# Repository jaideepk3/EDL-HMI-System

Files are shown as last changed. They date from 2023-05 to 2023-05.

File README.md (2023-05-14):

# HMI System for Corrosion Monitoring Product WEL-iPEC

This repository contains the development files for a Human Machine Interface (HMI) system designed for use with a corrosion monitoring product (iPEC-Probe). The HMI system includes a user interface with buttons connected to a microcontroller. Due to the unavailability of direct connection with the iPEC Probe, various sensors have been used to simulate data that will be displayed on the LCD screen.

## Files

The repository consists of the following files:

- **Packaging Enclosure CAD**: This folder contains CAD files for the packaging enclosure of the HMI system.

- **Board Files**: This folder contains the PCB design files for the microcontroller board.

- **HMI Code**: This folder contains the complex code that runs the HMI system.

- **Project Report**: This file is a comprehensive documented report of the entire project. It provides detailed information about the development process, implementation, and results. [Download Project Report](https://github.com/jaideepk3/EDL-HMI-System/blob/main/TUES-25_final_report.pdf)

## Project Description

### Aim
The aim of this project is to develop an HMI system that interfaces with the iPEC-Probe corrosion monitoring product. The HMI system will provide a user interface with buttons connected to a microcontroller. To simulate real-time data, sensors have been utilized instead of the actual iPEC Probe.

### Description
The project utilizes a Raspberry Pi Pico microcontroller board as the central controller for the HMI system. The microcontroller board interfaces with various buttons and an LCD screen. The buttons enable user interaction with the LCD screen, while the microcontroller controls the display based on the button inputs.

The HMI system displays real-time measurements obtained from various sensors, including the distance traveled from the scanning start point, rebar depth, rebar size, and other parameters. This provides users with an overview of the concrete structure's condition, enabling informed decision-making. The simulated values from the sensors facilitate comprehensive testing of the HMI system.

## Getting Started

To get started with the HMI system development, follow these steps:

1. Clone this repository to your local machine.
2. Navigate to the respective folders to access the CAD files, board design files, and HMI code.
3. Refer to the documentation provided in the report for further instructions.

## Additional Resources

- **Demo Video**: Watch a breadboard circuit demonstration of the HMI system in action. [Watch Demo Video](https://drive.google.com/file/d/1d6G7GhgJb7exQOc0swpD6kvzHQxaDGIW/view?usp=drivesdk)

- **Final Presentation**: Access the final presentation video for a detailed overview of the project. [View Final Presentation](https://drive.google.com/file/d/1m0dKYORe6IZ8-cWrcGXbmrLrGEMQUf9Z/view?usp=share_link)

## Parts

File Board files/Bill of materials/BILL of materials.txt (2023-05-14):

Partlist exported from C:/Users/seepa/AppData/Local/Temp/Neutron/ElectronFileOutput/8160/sch-04a15b2c-18d9-40eb-af97-f162f59256a9/Schematic v3.sch at 28-04-2023 18:17

Part               Value      Device                Package     Description                                      CATEGORY  DESCRIPTION                            MANUFACTURER MPN   OPERATING_TEMP OPERATING_TEMPERATURE PART_STATUS ROHS_COMPLIANCE ROHS_COMPLIANT SERIES SUB-CATEGORY THERMALLOSS TYPE       
GREEN_LED1         3MM_LED_TH 3MM_LED_TH            LED3MM                                                                                                                                                                                                                                                      
GREEN_LED2         3MM_LED_TH 3MM_LED_TH            LED3MM                                                                                                                                                                                                                                                      
GREEN_LED3         3MM_LED_TH 3MM_LED_TH            LED3MM                                                                                                                                                                                                                                                      
GREEN_LED4         3MM_LED_TH 3MM_LED_TH            LED3MM                                                                                                                                                                                                                                                      
GREEN_LED5         3MM_LED_TH 3MM_LED_TH            LED3MM                                                                                                                                                                                                                                                      
GREEN_LED6         3MM_LED_TH 3MM_LED_TH            LED3MM                                                                                                                                                                                                                                                      
JP2                PINHD-1X5  PINHD-1X5             1X05        PIN HEADER                                       CONNECTOR                                                                                                                                                  PIN-HEADER                          
JP4                PINHD-1X1  PINHD-1X1             1X01        PIN HEADER                                       CONNECTOR                                                                                                                                                  PIN-HEADER                          
JP5                PINHD-1X1  PINHD-1X1             1X01        PIN HEADER                                       CONNECTOR                                                                                                                                                  PIN-HEADER                          
JP6                PINHD-1X4  PINHD-1X4             1X04        PIN HEADER                                       CONNECTOR                                                                                                                                                  PIN-HEADER                          
JP7                PINHD-1X1  PINHD-1X1             1X01        PIN HEADER                                       CONNECTOR                                                                                                                                                  PIN-HEADER                          
JP10               PINHD-1X1  PINHD-1X1             1X01        PIN HEADER                                       CONNECTOR                                                                                                                                                  PIN-HEADER                          
JP11               PINHD-1X1  PINHD-1X1             1X01        PIN HEADER                                       CONNECTOR                                                                                                                                                  PIN-HEADER                          
JP12               PINHD-1X1  PINHD-1X1             1X01        PIN HEADER                                       CONNECTOR                                                                                                                                                  PIN-HEADER                          
JP14               PINHD-1X2  PINHD-1X2             1X02        PIN HEADER                                       CONNECTOR                                                                                                                                                  PIN-HEADER                          
JP15               PINHD-1X2  PINHD-1X2             1X02        PIN HEADER                                       CONNECTOR                                                                                                                                                  PIN-HEADER                          
LCD_SCREEN         ILI9341    ILI9341               ILI9341                                                                                                                                                                                                                                                     
R1                 10K        RESISTOR_1/4W_0207/10 0207/10                                                                                                                                                                                                                                                     
R2                 10K        RESISTOR_1/4W_0207/10 0207/10                                                                                                                                                                                                                                                     
R3                 10k        RESISTOR_1/4W_0207/10 0207/10                                                                                                                                                                                                                                                     
R4                 10K        RESISTOR_1/4W_0207/10 0207/10                                                                                                                                                                                                                                                     
R5                 10K        RESISTOR_1/4W_0207/10 0207/10                                                                                                                                                                                                                                                     
R6                 10k        RESISTOR_1/4W_0207/10 0207/10                                                                                                                                                                                                                                                     
R7                 10k        RESISTOR_1/4W_0207/10 0207/10                                                                                                                                                                                                                                                     
R8                 10k        RESISTOR_1/4W_0207/10 0207/10                                                                                                                                                                                                                                                     
R11                           PV36Y                 PV36Y       Rectangular Trimmer Potentiometers - PV36 Series Resistor  Lead Sealed Type Multiturn PV36 Series BOURNS       PV36Y                -55 to +125 °C        Active      ROHS Compliant                 PV36   Trimpot                  Lead Sealed
RASPBERRY_PI_PICO             RPI_PICO_IG-TH        RPI_PICO_TH                                                                                                                                                                                                                                                 
S1                 DTS-6      DTS-6                 DTS-6                                                                                                                                                                                                                                                       
S2                 DTS-6      DTS-6                 DTS-6                                                                                                                                                                                                                                                       
TEMPERATURE_SENSOR LM35CZ     LM35CZ                TO92        Single-Supply Centigrade Temperature Sensor

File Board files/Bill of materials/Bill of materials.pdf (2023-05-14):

Schematic v3

Part | Value | Device | Package
GREEN_LED1 | 3MM_LED_TH 3MM_LED_TH | LED3MM
GREEN_LED2 | 3MM_LED_TH 3MM_LED_TH | LED3MM
GREEN_LED3 | 3MM_LED_TH 3MM_LED_TH | LED3MM
GREEN_LED4 | 3MM_LED_TH 3MM_LED_TH | LED3MM
GREEN_LED5 | 3MM_LED_TH 3MM_LED_TH | LED3MM
GREEN_LED6 | 3MM_LED_TH 3MM_LED_TH | LED3MM
JP2 | PINHD-1X5 | PINHD-1X5 | 1X05
JP4 | PINHD-1X1 | PINHD-1X1 | 1X01
JP5 | PINHD-1X1 | PINHD-1X1 | 1X01
JP6 | PINHD-1X4 | PINHD-1X4 | 1X04
JP7 | PINHD-1X1 | PINHD-1X1 | 1X01
JP10 | PINHD-1X1 | PINHD-1X1 | 1X01
JP11 | PINHD-1X1 | PINHD-1X1 | 1X01
JP12 | PINHD-1X1 | PINHD-1X1 | 1X01
JP14 | PINHD-1X2 | PINHD-1X2 | 1X02
JP15 | PINHD-1X2 | PINHD-1X2 | 1X02
LCD_SCREEN | ILI9341 | ILI9341 | ILI9341
R1 | 10K | RESISTOR_1/4W_0207/10 0207/10
R2 | 10K | RESISTOR_1/4W_0207/10 0207/10
R3 | 10k | RESISTOR_1/4W_0207/10 0207/10
R4 | 10K | RESISTOR_1/4W_0207/10 0207/10
R5 | 10K | RESISTOR_1/4W_0207/10 0207/10
R6 | 10k | RESISTOR_1/4W_0207/10 0207/10
R7 | 10k | RESISTOR_1/4W_0207/10 0207/10
R8 | 10k | RESISTOR_1/4W_0207/10 0207/10
R11 | | PV36Y | PV36Y
RASPBERRY_PI_PICO | | RPI_PICO_IG-TH | RPI_PICO_TH
S1 | DTS-6 | DTS-6 | DTS-6
S2 | DTS-6 | DTS-6 | DTS-6
TEMPERATURE_SENSOR LM35CZ | LM35CZ | TO92

Description | CATEGORY
PIN HEADER | CONNECTOR
PIN HEADER | CONNECTOR
PIN HEADER | CONNECTOR
PIN HEADER | CONNECTOR
PIN HEADER | CONNECTOR
PIN HEADER | CONNECTOR
PIN HEADER | CONNECTOR
PIN HEADER | CONNECTOR
PIN HEADER | CONNECTOR
PIN HEADER | CONNECTOR

Rectangular Trimmer Potentiometers - PV36 Series Resistor

Single-Supply Centigrade Temperature Sensor

DESCRIPTION | MANUFACTURER MPN | OPERATING_TEMP
Lead Sealed Type Multiturn PV36 Series BOURNS | PV36Y

OPERATING_TEMPERATURE PART_STATUS ROHS_COMPLIANCE ROHS_COMPLIANT SERIES

-55 to +125 °C | Active | ROHS Compliant | PV36

SUB-CATEGORY THERMALLOSS TYPE

PIN-HEADER
PIN-HEADER
PIN-HEADER
PIN-HEADER
PIN-HEADER
PIN-HEADER
PIN-HEADER
PIN-HEADER
PIN-HEADER
PIN-HEADER
Trimpot | Lead Sealed

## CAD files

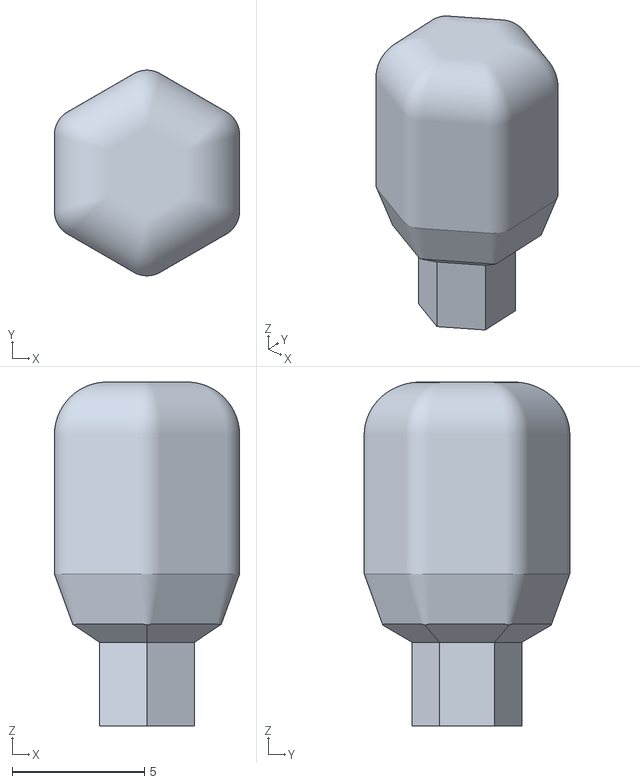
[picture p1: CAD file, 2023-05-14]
CAD files/3d print/Knob.stl
7.00 x 7.77 x 13.0

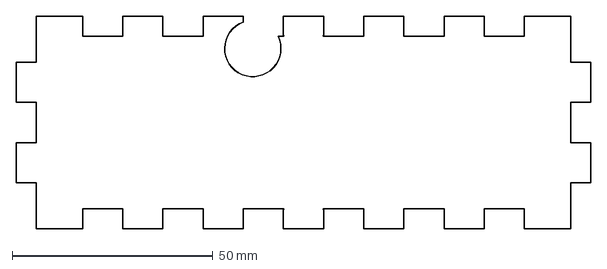
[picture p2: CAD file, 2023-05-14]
CAD files/lasercut/body1.dxf
143.2 x 53.0 mm

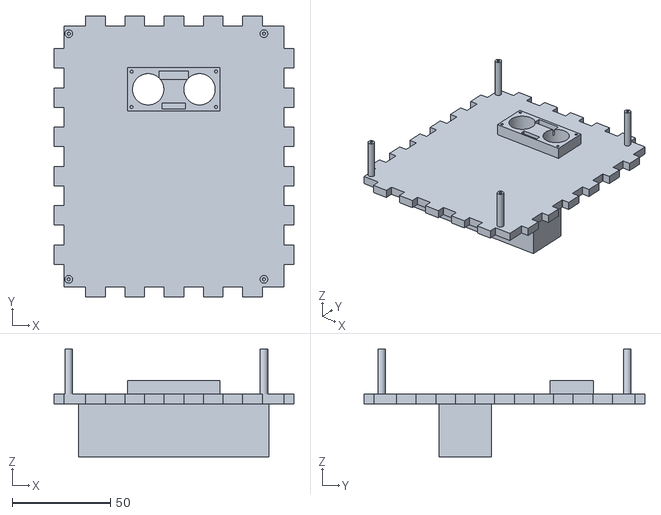
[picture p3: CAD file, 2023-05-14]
CAD files/3d print/body6.stl
122.3 x 143.2 x 55.0

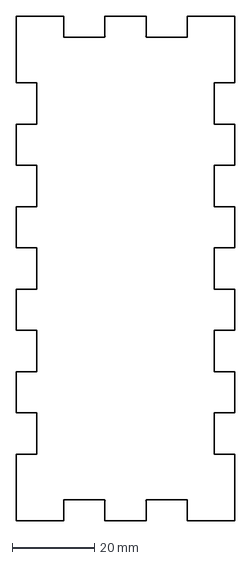
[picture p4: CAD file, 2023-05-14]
CAD files/lasercut/body5.dxf
53.0 x 122.3 mm

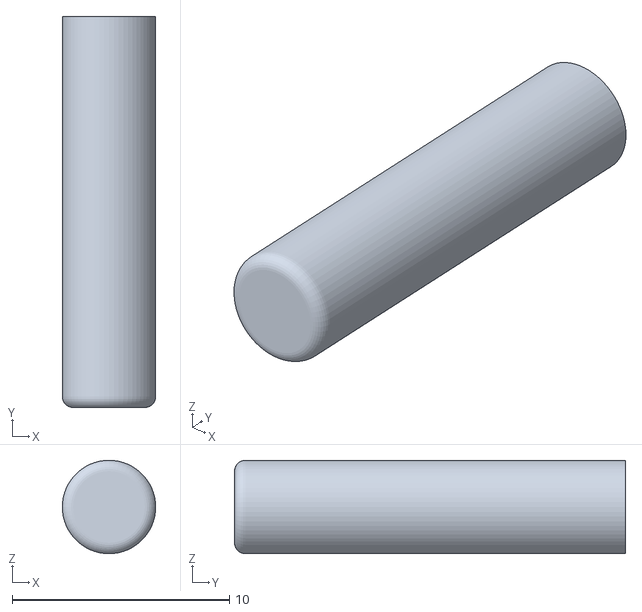
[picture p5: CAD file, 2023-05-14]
CAD files/3d print/Button_cap_X2.stl
4.30 x 18.0 x 4.30

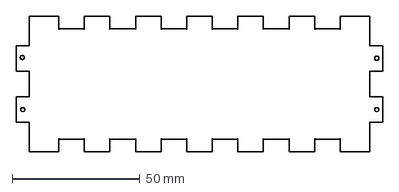
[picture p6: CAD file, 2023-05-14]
CAD files/lasercut/body4.dxf
143.2 x 53.0 mm

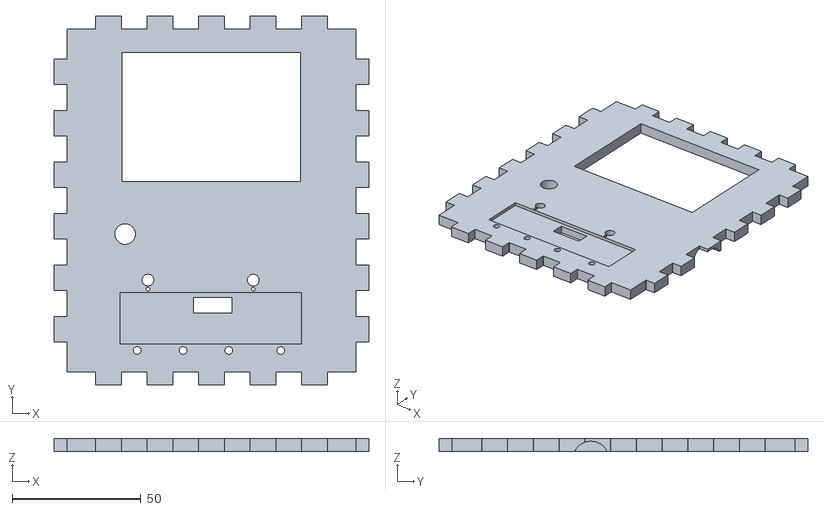
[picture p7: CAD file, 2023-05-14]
CAD files/3d print/body3.stl
122.3 x 143.2 x 5.00

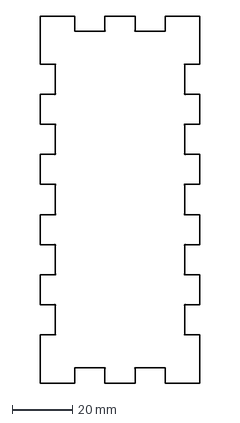
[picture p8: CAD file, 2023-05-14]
CAD files/lasercut/body2.dxf
53.0 x 122.3 mm

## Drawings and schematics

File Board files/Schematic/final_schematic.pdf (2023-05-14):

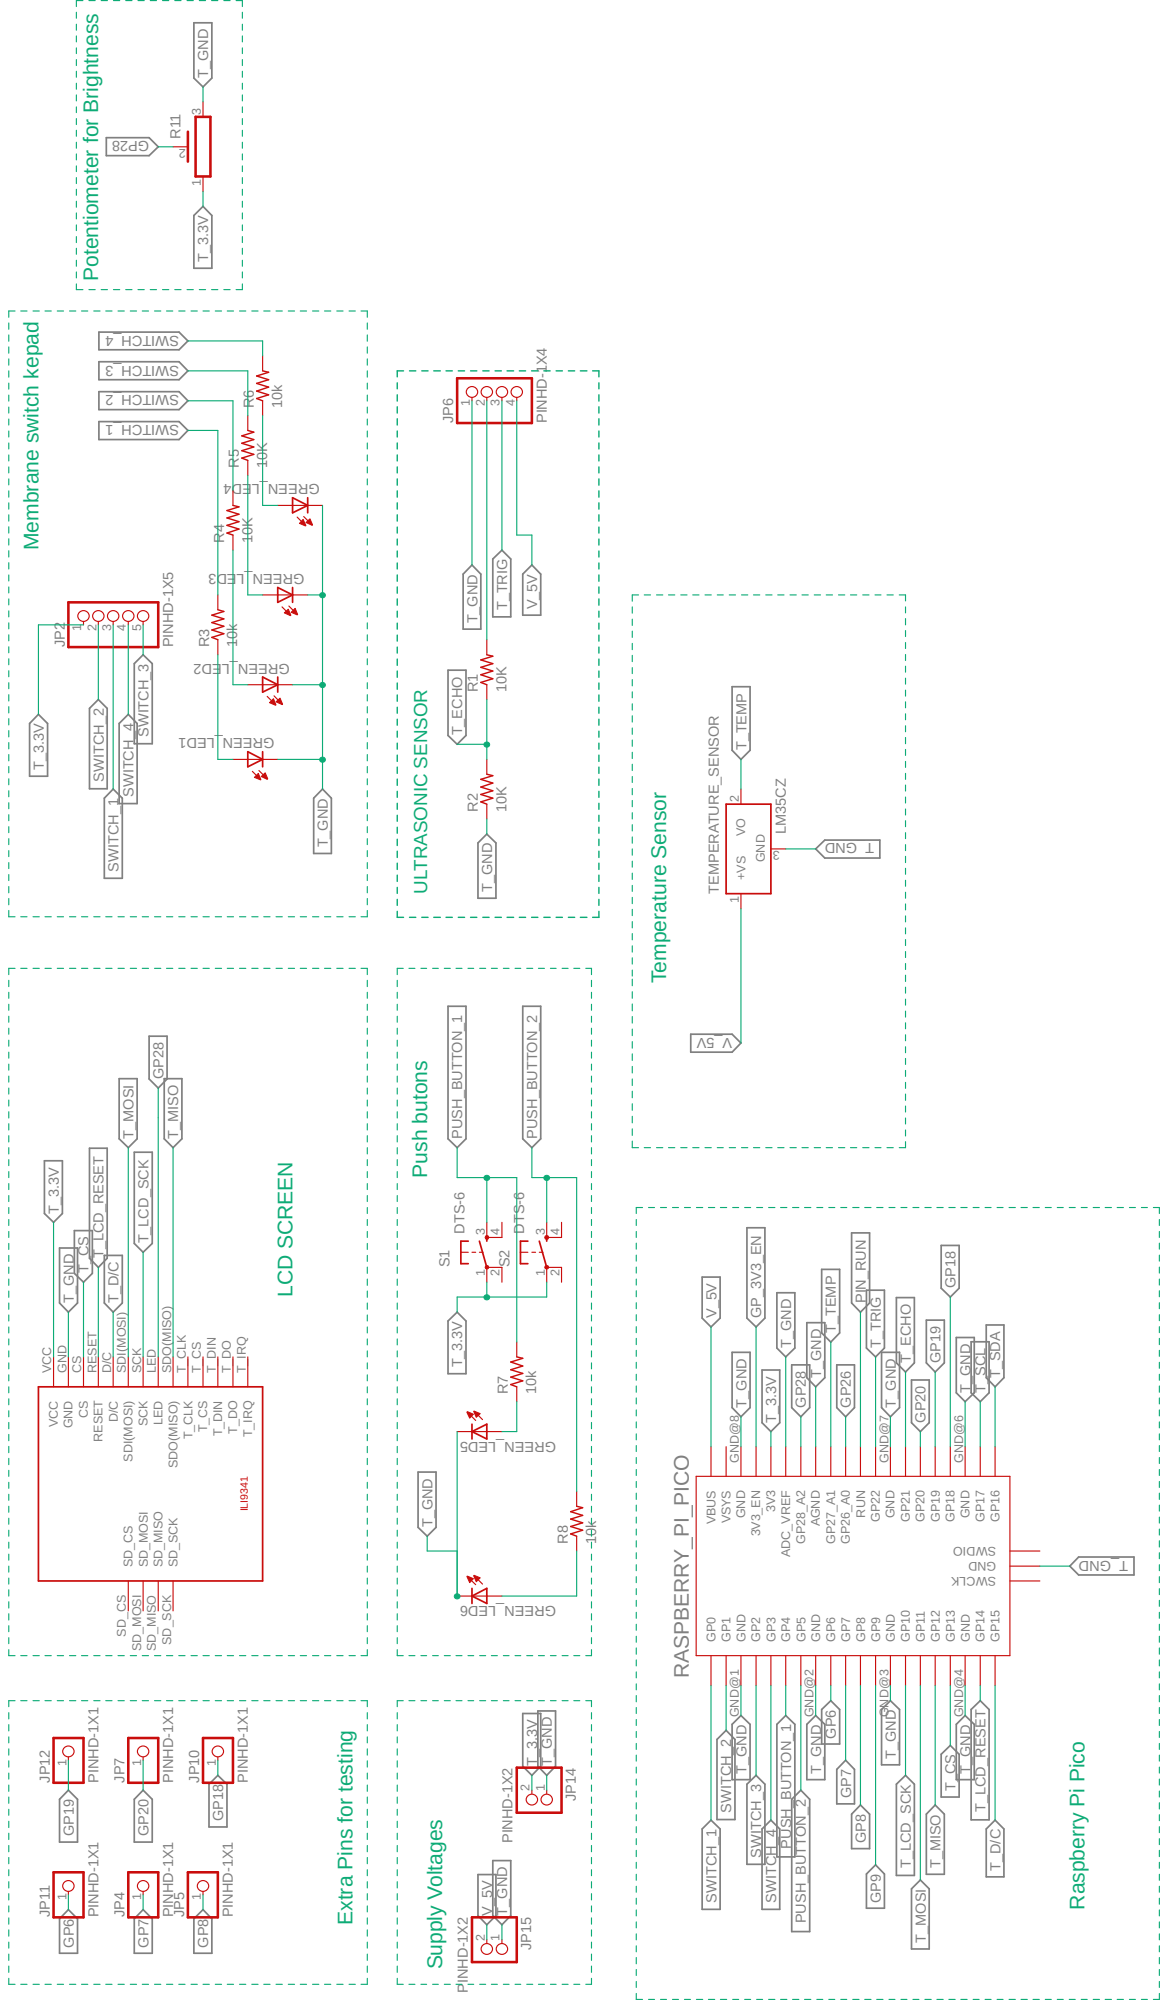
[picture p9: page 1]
5 T_ECHO T_ECHO T_TEMP T_TEMP T_3.3V T_3.3V T_3.3V T_3.3V T_3.3V T_3.3V T_GND T_GND T_GND

LM35CZ 10K 10K 10k 10K 10K 10k 10k 10k PINHD-1X1 PINHD-1X1 PINHD-1X1 PINHD-1X1 PINHD-1X1 PINHD-1X1 PINHD-1X2 PINHD-1X2 DTS-6 DTS-6 PINHD-1X4 PINHD-1X5 RASPBERRY_PI_PICO GP0 GP1 GP2 GP3 GP4 GP5 GP6 GP7 GP8 GP9 GP10 GP11 GP12 GP13 GP14 GP15 RUN GP22 GP21 GP20 GP19 GP18 GP17 GP16 GP27_A1 GP26_A0 AGND GP28_A2 ADC_VREF 3V3 3V3_EN VBUS VSYS

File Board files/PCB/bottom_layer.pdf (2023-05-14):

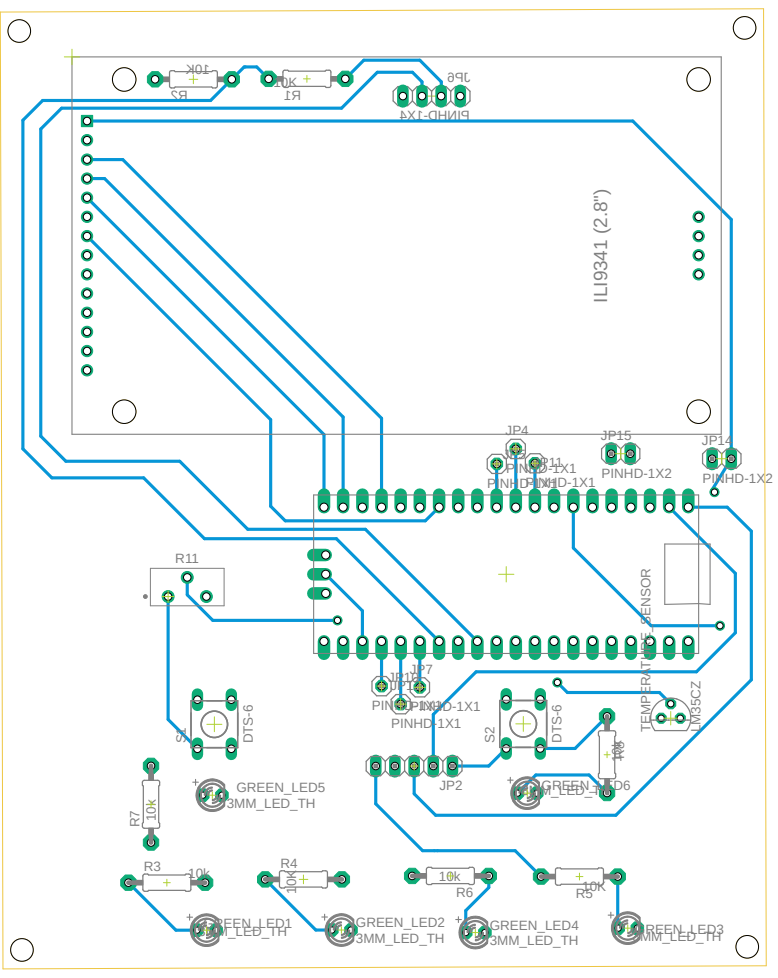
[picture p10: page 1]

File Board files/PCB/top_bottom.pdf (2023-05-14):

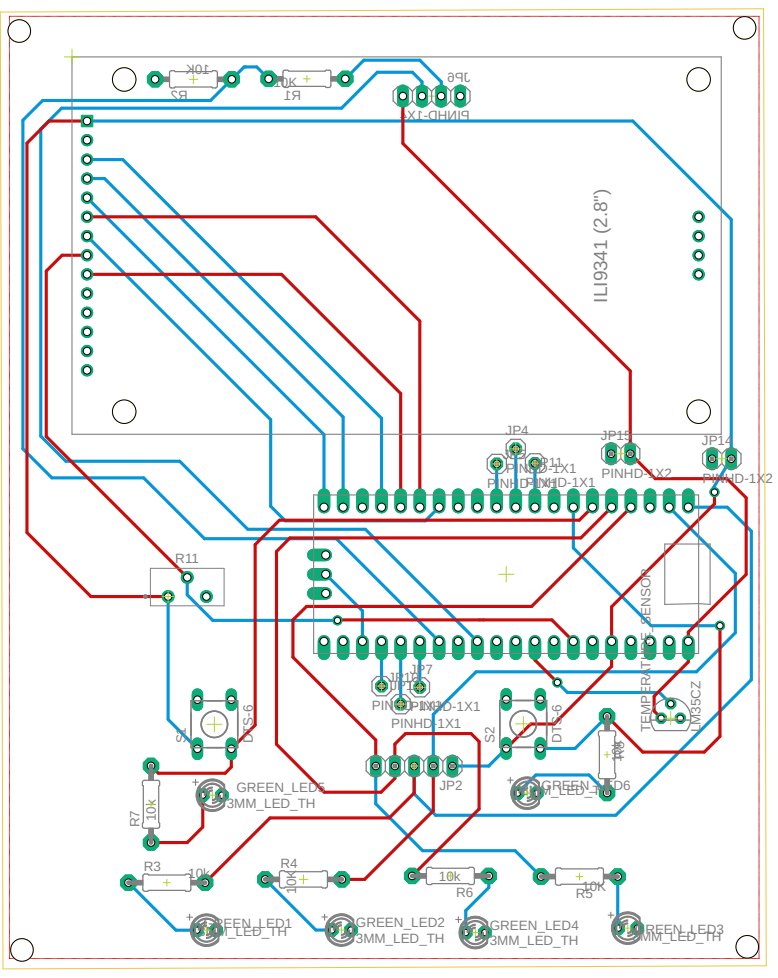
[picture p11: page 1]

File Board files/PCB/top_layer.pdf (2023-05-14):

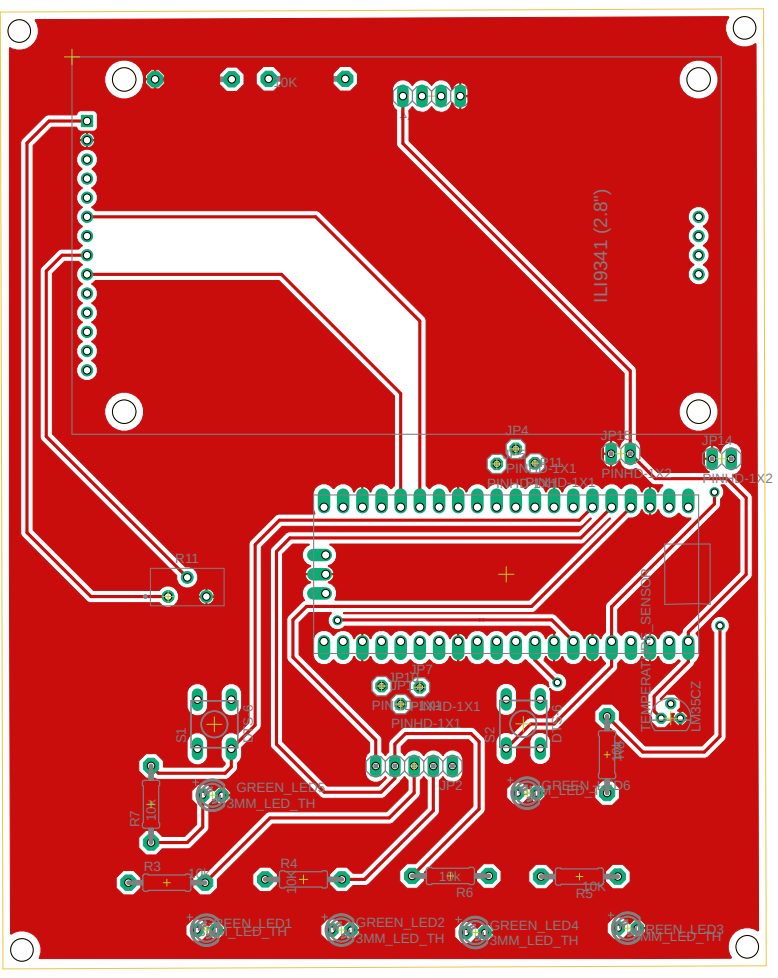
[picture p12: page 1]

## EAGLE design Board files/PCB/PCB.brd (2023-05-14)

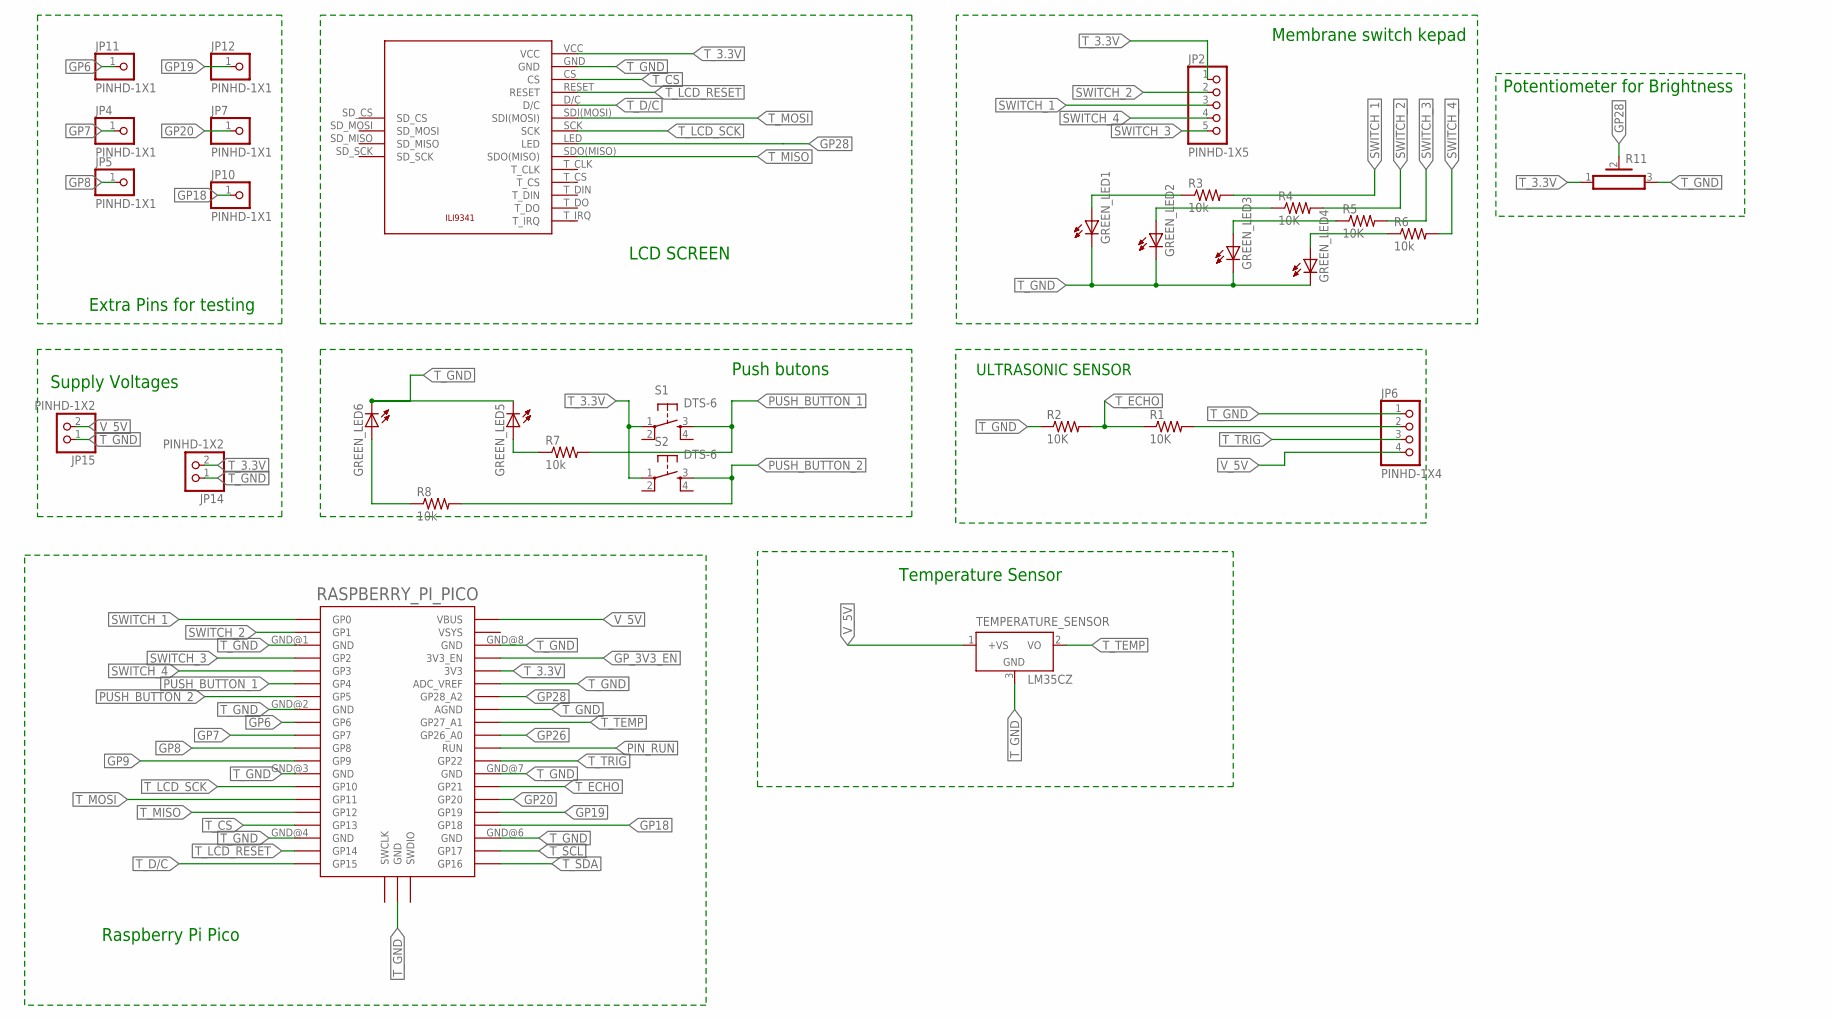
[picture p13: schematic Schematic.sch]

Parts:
GREEN_LED1, GREEN_LED2, GREEN_LED3, GREEN_LED4, GREEN_LED5, GREEN_LED6: 3MM_LED_TH; LED3MM
JP2: PINHD-1X5; 1X05
JP4, JP5, JP7, JP10, JP11, JP12: PINHD-1X1; 1X01
JP6: PINHD-1X4; 1X04
JP14, JP15: PINHD-1X2; 1X02
LCD_SCREEN: ILI9341
R1, R2, R4, R5: 10K; 0207/10
R3, R6, R7, R8: 10k; 0207/10
R11: PV36Y
RASPBERRY_PI_PICO: RPI_PICO_IG-TH; RPI_PICO_TH
S1, S2: DTS-6
TEMPERATURE_SENSOR: LM35CZ; TO92

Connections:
GP6: JP11.1, RASPBERRY_PI_PICO.GP6
GP7: JP4.1, RASPBERRY_PI_PICO.GP7
GP8: JP5.1, RASPBERRY_PI_PICO.GP8
GP9: RASPBERRY_PI_PICO.GP9
GP18: JP10.1, RASPBERRY_PI_PICO.GP18
GP19: JP12.1, RASPBERRY_PI_PICO.GP19
GP20: JP7.1, RASPBERRY_PI_PICO.GP20
GP26: RASPBERRY_PI_PICO.GP26_A0
GP28: LCD_SCREEN.LED, R11.2, RASPBERRY_PI_PICO.GP28_A2
GP_3V3_EN: RASPBERRY_PI_PICO.3V3_EN
unnamed: JP6.2, R1.2
unnamed: GREEN_LED4.A, R6.1
unnamed: GREEN_LED3.A, R5.1
unnamed: GREEN_LED2.A, R4.1
unnamed: GREEN_LED1.A, R3.1
unnamed: GREEN_LED5.A, R7.1
unnamed: GREEN_LED6.A, R8.1
PIN_RUN: RASPBERRY_PI_PICO.RUN
PUSH_BUTTON_1: R7.2, RASPBERRY_PI_PICO.GP4, S1.3
PUSH_BUTTON_2: R8.2, RASPBERRY_PI_PICO.GP5, S2.3
SWITCH_1: JP2.3, R3.2, RASPBERRY_PI_PICO.GP0
SWITCH_2: JP2.2, R4.2, RASPBERRY_PI_PICO.GP1
SWITCH_3: JP2.5, R5.2, RASPBERRY_PI_PICO.GP2
SWITCH_4: JP2.4, R6.2, RASPBERRY_PI_PICO.GP3
T_3.3V: JP2.1, JP14.2, LCD_SCREEN.VCC, R11.1, RASPBERRY_PI_PICO.3V3, S1.1, S2.1
T_CS: LCD_SCREEN.CS, RASPBERRY_PI_PICO.GP13
T_D/C: LCD_SCREEN.D/C, RASPBERRY_PI_PICO.GP15
T_ECHO: R1.1, R2.2, RASPBERRY_PI_PICO.GP21
T_GND: GREEN_LED1.K (C), GREEN_LED2.K (C), GREEN_LED3.K (C), GREEN_LED4.K (C), GREEN_LED5.K (C), GREEN_LED6.K (C), JP6.1, JP14.1, JP15.1, LCD_SCREEN.GND, R2.1, R11.3, RASPBERRY_PI_PICO.ADC_VREF, RASPBERRY_PI_PICO.AGND, RASPBERRY_PI_PICO.GND@1 (GND), RASPBERRY_PI_PICO.GND@2 (GND), RASPBERRY_PI_PICO.GND@3 (GND), RASPBERRY_PI_PICO.GND@4 (GND), RASPBERRY_PI_PICO.GND@5 (GND), RASPBERRY_PI_PICO.GND@6 (GND), RASPBERRY_PI_PICO.GND@7 (GND), RASPBERRY_PI_PICO.GND@8 (GND), TEMPERATURE_SENSOR.3 (GND)
T_LCD_RESET: LCD_SCREEN.RESET, RASPBERRY_PI_PICO.GP14
T_LCD_SCK: LCD_SCREEN.SCK, RASPBERRY_PI_PICO.GP10
T_MISO: LCD_SCREEN.SDO(MISO), RASPBERRY_PI_PICO.GP12
T_MOSI: LCD_SCREEN.SDI(MOSI), RASPBERRY_PI_PICO.GP11
T_SCL: RASPBERRY_PI_PICO.GP17
T_SDA: RASPBERRY_PI_PICO.GP16
T_TEMP: RASPBERRY_PI_PICO.GP27_A1, TEMPERATURE_SENSOR.2 (VO)
T_TRIG: JP6.3, RASPBERRY_PI_PICO.GP22
V_5V: JP6.4, JP15.2, RASPBERRY_PI_PICO.VBUS, TEMPERATURE_SENSOR.1 (+VS)

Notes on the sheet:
LCD SCREEN
ULTRASONIC SENSOR
Membrane switch kepad
Push butons
Supply Voltages
Extra Pins for testing
Raspberry Pi Pico
Potentiometer for Brightness
Temperature Sensor

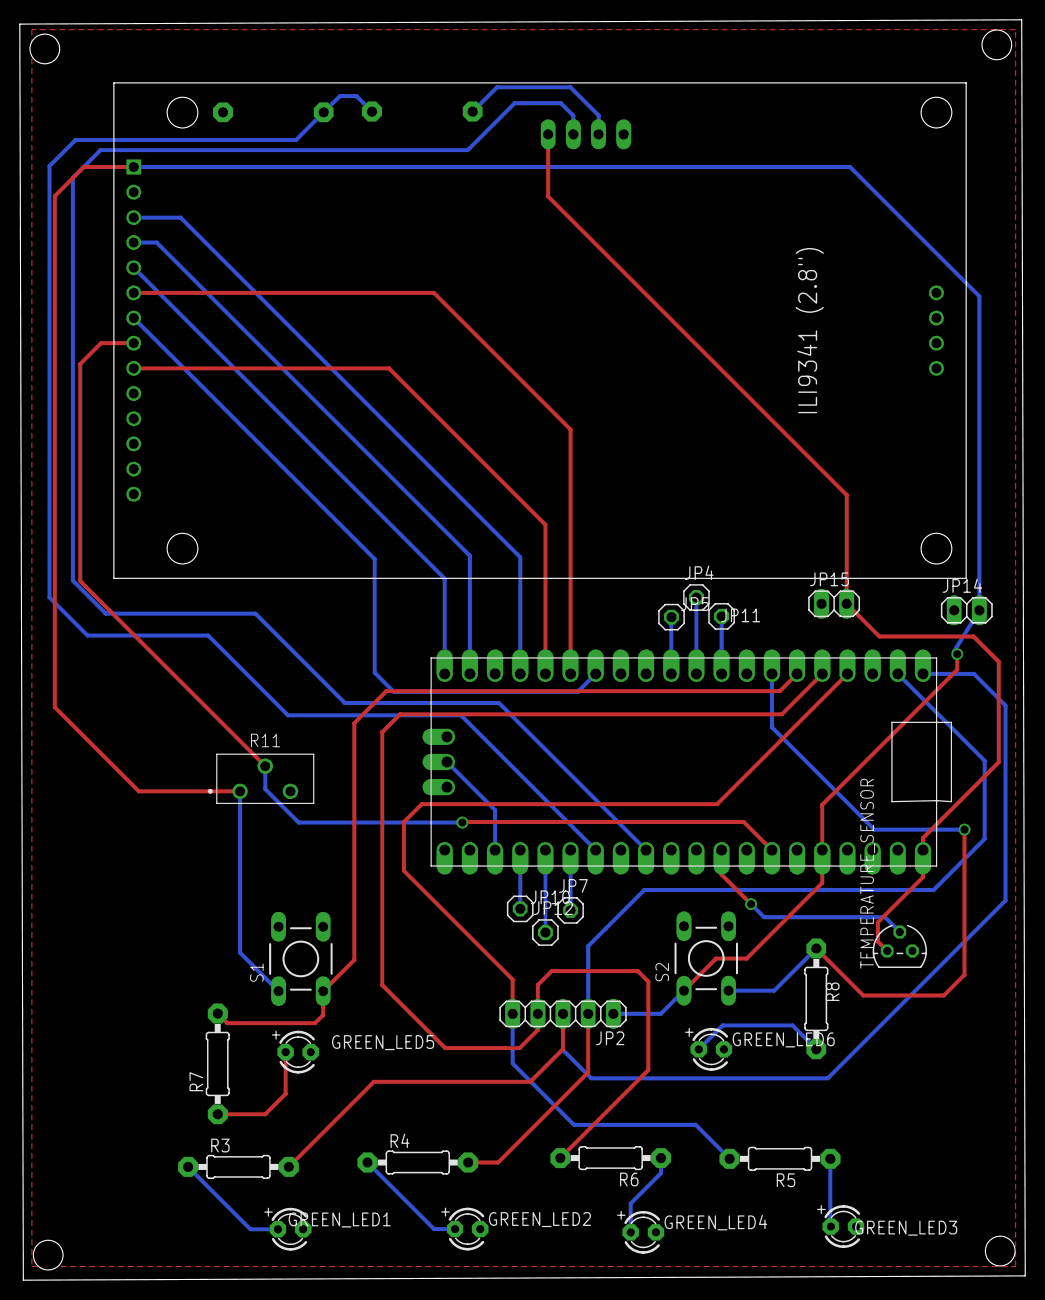
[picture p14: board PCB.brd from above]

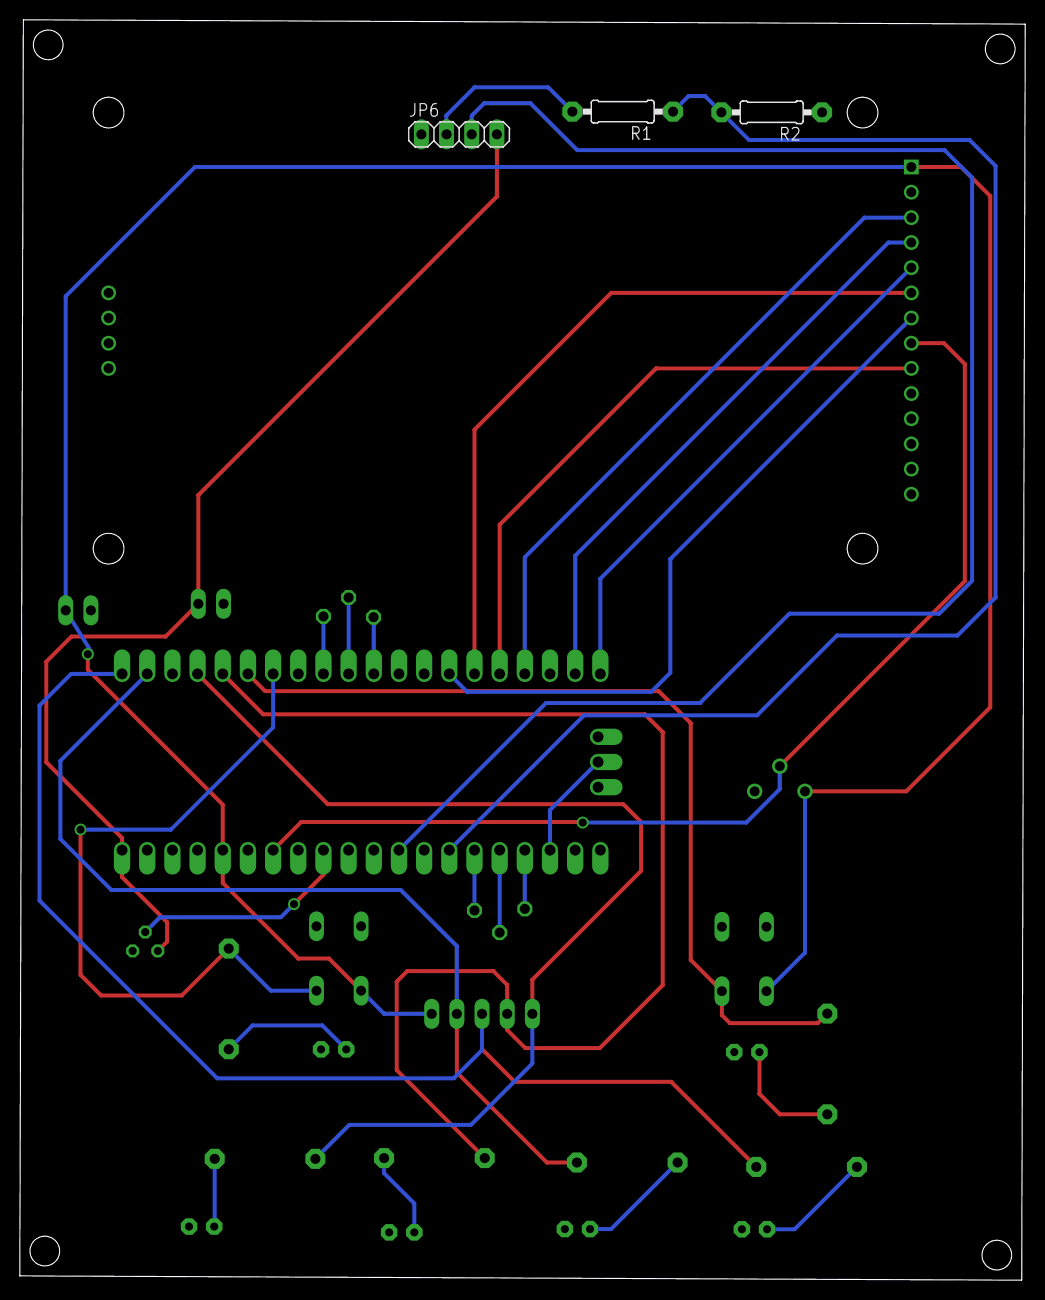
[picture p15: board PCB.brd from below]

Board: 2 copper layers, 101.5 x 127.2 mm, 30 parts (3 on the bottom side), 32 nets.

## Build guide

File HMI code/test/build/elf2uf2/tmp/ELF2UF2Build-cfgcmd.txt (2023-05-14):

cmd='C:/Program Files/CMake/bin/cmake.exe;-GMinGW Makefiles;-S;<SOURCE_DIR><SOURCE_SUBDIR>;-B;<BINARY_DIR>'

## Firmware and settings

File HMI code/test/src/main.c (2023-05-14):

#include "main.h"
#include "ui.h"
#include "interface.h"
#include "temp.h"
#include "pico/time.h"
#include <string.h>
#include "pico/stdlib.h"
#include "hardware/gpio.h"
#include "hardware/adc.h"
#include "./screens/simulator_screen.h"
#include "./screens/distance_screen.h"
#include "simulation.h"
#include "distance.h"
 #include "./screens/popup.h"
#include<stdint.h>
#include<stdlib.h>
#include "brightness.h"
float univ = 27;
int NUM_SCREENS = 4;
uint32_t curr_brightness =  0;
 uint8_t currPopupPage =0;
 int lastDetectedPress = 0;
GPU_Color BG_COLOR= BLACK;
int presses = 0;

bool pauseSimulation = false;
static uint32_t _lastDrawTime;
Screen currScreen = DISTANCE_SCREEN;
#define INTERVAL 5*1e6

float random_wait_time(int maxtime){
    return  (((float) rand() / (float)(RAND_MAX))*maxtime);
}

  
int end=-1;
int dist;
int new_draw_time;


//update rebar depth on simulation screen 
void distance_callback(){
    dist = (int)calc_distance();
    end+=1;
    if(end>=Q_SIZE)end=Q_SIZE;
    simulate(end,dist);
    busy_wait_ms(130);
}

void DoMainLoop()
{   
    _lastDrawTime = IF_GetCurrentTime();
  distance_sensor_init();
  bar_init();
  temp_sensor_init();
  simulation_init();
  distance_screen_init();
 
    int old=time_us_32();
    lastDetectedPress = time_us_32();
 

    while (1)
    {
       int now = time_us_32();
        //Register left keyboard events
        Keyboard();

        //update UI if popup isn't opened and achieve desired FPS
             if (( new_draw_time - _lastDrawTime > (ONE_SECOND/GPU_TARGET_FPS)) && !popup_opened)
             {
              _lastDrawTime = new_draw_time;
              GPU_Render(); //update UI on LCD screen
       } new_draw_time= IF_GetCurrentTime();
 
//rebar simulation done at regular intervals      
if((now-old>INTERVAL)&&(!pauseSimulation)){
    distance_callback();
    old=now;
}

//update UI on LCD based on current screen  
  if(currScreen ==DISTANCE_SCREEN){
   distance_screen_init();
  }
  else if(currScreen==PARAMS_SCREEN){
    update_temperature();
    display_png();//thermometer image

  }else if(currScreen == SIMULATION_SCREEN){
    display_simulation(end);
  }else if(currScreen == ADJUST_BRIGHTNESS_SCREEN) {
    brightness_screen_init();
    update_brightness();
    increase_brightness(curr_brightness);
 
  } else{
  GPU_ClearFramebuffers();
  }
  	 
  if(popup_opened){GPU_DrawFilledRectangle(BLACK,40,TOP_MARGIN,270,160);}
 
  
    }
}

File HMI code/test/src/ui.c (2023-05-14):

#include "ui.h"
#include "fonts.h"
#include <string.h>
#include <math.h>
#include "pico/time.h"
#include <stdio.h>
#include "interface.h"
//buffer to store pixel values
 uint16_t _framebuffer[GPU_X*GPU_Y];  // GPU VRAM (16bits per color)


void GPU_Init()
{  GPU_ClearFramebuffers();
}
 

void GPU_ClearFramebuffers()
{
    memset(_framebuffer, 0, sizeof(_framebuffer));
}



#define SHOW_FPS

#ifdef SHOW_FPS
uint32_t oldTime = 0;
#endif

uint32_t getMinutes(){
    uint32_t nowTime = IF_GetCurrentTime();
    uint32_t currentTime = to_ms_since_boot(nowTime)/1000;
        uint8_t seconds = ((currentTime/10%60)*10)%60;
     uint32_t minutes= currentTime/60;
     return minutes;
}

//update LCD screen pixel values by sending buffer data
void GPU_Render()
{ 
#ifdef SHOW_FPS
	char t[25] = "";
	uint16_t len = 0;
	uint32_t nowTime = IF_GetCurrentTime();

#define COLOR_INFO RGB(217,207,38)
	if (oldTime != nowTime)
	{   
		uint16_t fps = (float)ONE_SECOND / (float)(nowTime-oldTime);
        uint32_t currentTime = to_ms_since_boot(nowTime)/1000;
        uint8_t seconds = ((currentTime/10%60)*10)%60;
        uint32_t minutes= currentTime/60;
		len = sprintf(t, "On Time = %d min %d sec", minutes, seconds);
   
        GPU_DrawFilledRectangle(BG_COLOR,GPU_X-len*fontDescription[1].width - 10,0,
        len*fontDescription[1].width+30,fontDescription[1].height+1);
		GPU_DrawText(COLOR_INFO, &fontDescription[1], GPU_X-len*fontDescription[1].width, 0, t, len);
	}

	oldTime = nowTime;

#endif
    IF_DrawScreen((uint8_t *)_framebuffer, sizeof(_framebuffer));
}

///////////////////////////////////////////////

void GPU_DrawPixel(GPU_Color color, uint16_t x, uint16_t y)
{
    if (x >= GPU_X || y >= GPU_Y)
        return;
    uint16_t * pix = &_framebuffer[(GPU_X-x-1)*GPU_Y+y];
    (*pix) = (uint16_t) color;
}

void GPU_DrawLine(GPU_Color color, int16_t x0, int16_t y0, int16_t x1, int16_t y1)
{
    // Bresenhams line algorithm
    x0 = (x0 >= GPU_X) ? GPU_X-1 : x0;
    x1 = (x1 >= GPU_X) ? GPU_X-1 : x1;
    y0 = (y0 >= GPU_Y) ? GPU_Y-1 : y0;
    y1 = (y1 >= GPU_Y) ? GPU_Y-1 : y1;
    int16_t dx =  x1>x0 ? x1-x0 : x0-x1;
    int16_t sx = x0<x1 ? 1 : -1;
    int16_t dy = y1 > y0 ? -(y1-y0): y1-y0;
    int16_t sy = y0<y1 ? 1 : -1;
    int16_t err = dx+dy;  /* error value e_xy */
    while (1)   /* loop */
    {
        GPU_DrawPixel(color, x0, y0);
        if (x0 == x1 && y0 == y1) 
            break;
        int16_t e2 = 2*err;
        if (e2 >= dy) /* e_xy+e_x > 0 */
        {
            err += dy;
            x0 += sx;
        }
        if (e2 <= dx) /* e_xy+e_y < 0 */
        {
            err += dx;
            y0 += sy;
        }
    }
}

void GPU_DrawLetter(GPU_Color color, const FontDescription * fontDescription, int16_t x, int16_t y, char letter)
{
    for (uint16_t i=0; i<fontDescription->height; i++)
    {
        uint16_t current_pic = fontDescription->fontArray[(letter-32)*fontDescription->height+i];
        for (uint8_t j=0; j<fontDescription->width; j++)
        {
            if (current_pic & (1<<(16-j)))
                GPU_DrawPixel(color, x+j, y+i);
        }
    }
}

void GPU_DrawText(GPU_Color color, const FontDescription * fontDescription, int16_t x, int16_t y, const char * text, uint16_t len)
{
    for (uint16_t i=0; i<len; i++)
    {
        GPU_DrawLetter(color, fontDescription, x+i*fontDescription->width, y, text[i]);
    }
}

void GPU_DrawEmptyRectangle(GPU_Color color, int16_t x, int16_t y, int16_t width, int16_t height)
{
    GPU_DrawLine(color, x, y, x+width, y);
    GPU_DrawLine(color, x, y+height, x+width, y+height);
    GPU_DrawLine(color, x, y, x, y+height);
    GPU_DrawLine(color, x+width, y, x+width, y+height);
}

void GPU_DrawFilledRectangle(GPU_Color color, int16_t x, int16_t y, int16_t width, int16_t height)
{
    for (int16_t i=0; i<width; i++)
    {
        for (int16_t j=0; j<height; j++)
        {
            GPU_DrawPixel(color, x+i, y+j);
        }    
    }
}
void DrawSmoothBar(GPU_Color color, int16_t x, int16_t y, int16_t width, int16_t height)
{
    int radius = height/2;
    GPU_DrawFilledRectangle(color,x+radius,y,width,height);
    GPU_DrawFilledCircle(color,x+radius,y+radius,radius);
    GPU_DrawFilledCircle(color,x+width+radius,y+radius,radius);
    return;
}
 
void DrawVerticalRectangle(GPU_Color color, int16_t x, int16_t y, int16_t width, int16_t height)
{
    for (int16_t i=0; i<width; i++)
    {
        for (int16_t j=0; j<height; j++)
        {
            GPU_DrawPixel(color, x+i, y-j);
        }    
    }
}

void DrawFilledTriangle(GPU_Color color, int16_t x, int16_t y, int16_t side,int16_t height,char* dir){
    if(dir=="right"){
        for(int i=0;i<height;i++){
            for(int j=side/2-i;j>=0;j--){
                GPU_DrawPixel(color,x+i,y-j);
            }
        }
        for(int i=0;i<height;i++){
            for(int j=side/2-i;j>=0;j--){
                GPU_DrawPixel(color,x+i,y+j);
            }
        }
    }else if(dir=="left"){
        for(int i=0;i<height;i++){
            for(int j=side/2-i;j>=0;j--){
                GPU_DrawPixel(color,x-i,y-j);
            }
        }
        for(int i=0;i<height;i++){
            for(int j=side/2-i;j>=0;j--){
                GPU_DrawPixel(color,x-i,y+j);
            }
        }
    } 
    }


void LeftHalfFilledCircle(GPU_Color color, int16_t x, int16_t y, int16_t radius)
{
    uint16_t xd = 0, yd = radius;
    int16_t d = 3 - 2 * radius;
    int16_t mxxd = x-xd > 0 ? x-xd : 0;
    int16_t myyd = y-yd > 0 ? y-yd : 0;
    int16_t mxyd = x-yd > 0 ? x-yd : 0;
    int16_t myxd = y-xd > 0 ? y-xd : 0;
    GPU_DrawLine(color, mxxd, myyd, x, myyd);
    GPU_DrawLine(color, mxxd, y+yd, x, y+yd);
    GPU_DrawLine(color, mxyd, myxd, x, myxd);
    GPU_DrawLine(color, mxyd, y+xd, x, y+xd);
    while (yd >= xd)
    {
        xd++;
        if (d > 0)
        {
            yd--;
            d = d + 4 * (xd - yd) + 10;
        }
        else
            d = d + 4 * xd + 6;
        
        mxxd = x-xd > 0 ? x-xd : 0;
        myyd = y-yd > 0 ? y-yd : 0;
        mxyd = x-yd > 0 ? x-yd : 0;
        myxd = y-xd > 0 ? y-xd : 0;
        GPU_DrawLine(color, x-xd, y-yd, x , y-yd);
        GPU_DrawLine(color, x-xd, y+yd, x , y+yd);
        GPU_DrawLine(color, x-yd, y-xd, x , y-xd);
        GPU_DrawLine(color, x-yd, y+xd, x , y+xd);
    }
}
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
